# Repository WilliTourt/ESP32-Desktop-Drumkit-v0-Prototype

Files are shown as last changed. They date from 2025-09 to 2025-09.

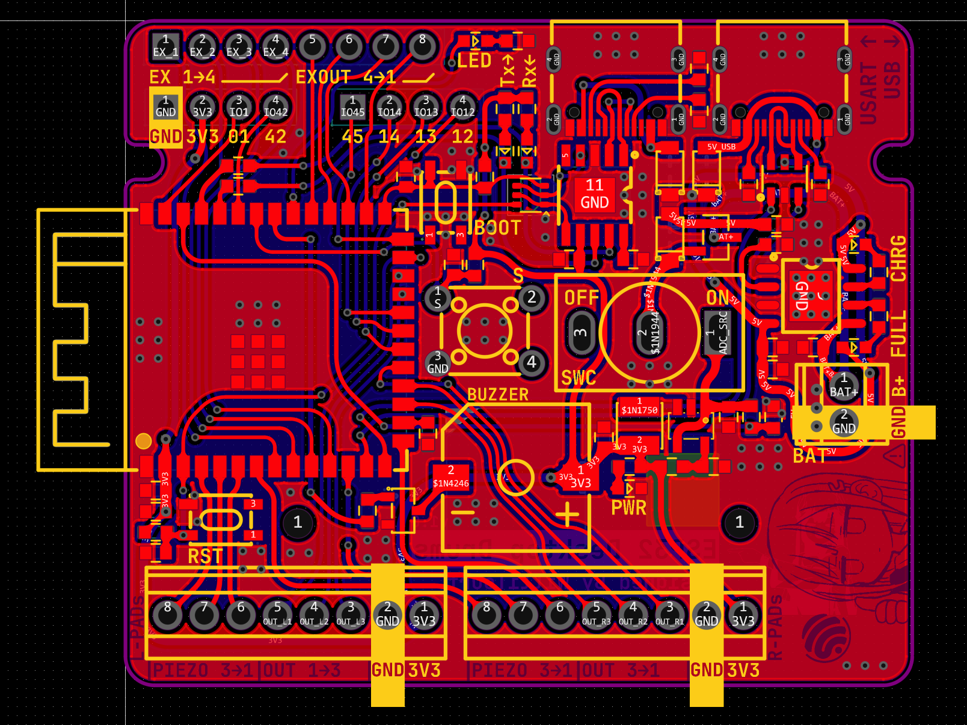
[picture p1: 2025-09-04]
Hardware_PCB/PCB Gerber/Images/ESP32 Top.png

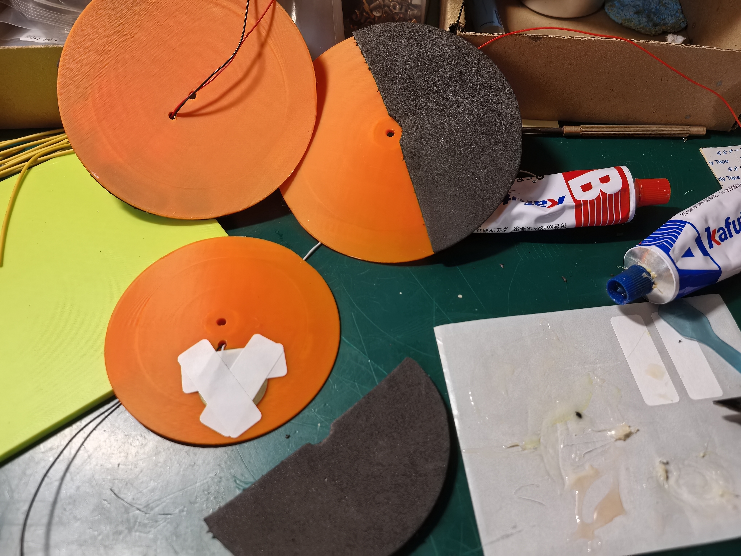
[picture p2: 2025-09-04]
Images of Drumkit/IMG_20250831_165159.jpg

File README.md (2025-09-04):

# ESP32 Desktop Drumkit v0 Prototype

> **Languages/语言**: [English](README.md) | [简体中文](README-zh-CN.md)

This is the English version of the README.

## Project Overview

This is an ESP32-based electronic drum pad prototype project supporting both BLE MIDI and serial MIDI output. The project includes multi-channel piezo drum pad/cymbal sensing, velocity normalization, dual-mode output (serial & BLE), and battery management.  
This project is suitable for DIY music enthusiasts, electronic drum developers, and embedded system learners for reference and further development.

---

## Features

- **Multi-Pad Sensing**: Supports multiple piezo sensors (drum pads, cymbals), each with independent threshold settings.
- **MIDI Output**:
  - **BLE MIDI** (wireless connection to phones/computers)
  - **Serial MIDI** (connects to PC via CH340/USB-to-serial, supported by Hairless MIDI bridge software)
- **Velocity Normalization**: Maps detected strike intensity to standard MIDI velocity (1-127).
- **Anti-Crosstalk Algorithm**: Only allows the pad with the highest ADC value to trigger during each sampling period, with silent periods for other pads to prevent false triggers.
- **Battery Voltage Management**: Supports battery monitoring and low-power alerts.
- **LED/Buzzer Indicators**: Mode switching and status feedback.
- **One-Button Mode Switching**: Toggle between BLE MIDI and Serial MIDI modes.
- **Enclosure Design**: Modular design for easy expansion.

---

## Hardware Specifications

- **Main Controller**: ESP32 (ESP32-S3 recommended for native USB support)
- **Piezo Elements**: ≥42mm for drum pads, 27mm for cymbals; *strongly* recommend shielded signal wires with parallel 0.1μF~1μF ceramic capacitors
- **Serial Chip**: CH340 (or other USB-UART converters)
- **Battery**: Optional lithium battery with voltage monitoring circuit
- **Others**: LEDs, buzzer, buttons - see `def.h` for peripheral interfaces
- 
### Sensor Connection/External Circuit

- Refer to [Images of Drumkit](https://github.com/WilliTourt/ESP32-Desktop-Drumkit-v0-Prototype/tree/main/Images%20of%20Drumkit) and [Hardware_PCB](https://github.com/WilliTourt/ESP32-Desktop-Drumkit-v0-Prototype/tree/main/Hardware_PCB)
- The external circuit uses quick-connect plugs to interface piezo elements through a simple voltage divider board before connecting to the main controller
- Main board IOs are labeled PIEZO (ADC input for piezo elements) and OUT (originally intended for LED effects but unused in this prototype)

### 3D Enclosure Files

- Final assembled appearance shown in [Images of Drumkit](https://github.com/WilliTourt/ESP32-Desktop-Drumkit-v0-Prototype/tree/main/Images%20of%20Drumkit)
- Designed as a miniature version of a real electronic drum set
- Main flaw: pads/cymbals don't properly account for vibration transmission
- Base plate split into L/R sections due to 3D printer size limitations
- L/R circuits connected via magnetic connectors (2/4-pin with screw holes, producer: pogopin)

---

## Software Specifications

- **PlatformIO/Arduino compatible**, PlatformIO with Arduino framework recommended
- **Dependencies**:
  - `BLEMIDI_Transport` / `hardware/BLEMIDI_ESP32`
  - `OneButtonTiny` (button detection)
  - See source code headers for others

---

## Usage Instructions

### 1. Hardware Setup

- Connect piezo elements to GPIO as defined in `def.h`
- Connect serial TX/RX to computer via CH340 (recognized as COM port)
- BLE MIDI supports phone/computer Bluetooth connections
- Button for mode switching

### 2. Compilation & Flashing

- Using PlatformIO: `pio run -t upload`
- Or Arduino IDE: select correct board and port

### 3. MIDI Output

#### Serial MIDI

- Open [Hairless MIDI <-> Serial Bridge](https://projectgus.github.io/hairless-midiserial/) or [loopMIDI](https://www.tobias-erichsen.de/software/loopmidi.html)
- Set baud rate to 115200 (matches code)
- After bridging, DAW/audio software can recognize virtual MIDI port

#### BLE MIDI

- Connect Bluetooth device to "ESP32 Desktop DrumKit v0"
- DAW or mobile MIDI apps can directly recognize

### 4. Anti-Interference Notes

- Only the pad with highest ADC value triggers per sampling period, others enter silent period (software anti-crosstalk)
- Independent threshold settings for pads/cymbals (see `Pad` constructor parameters)
- For extreme false triggers, adjust thresholds, silent periods, or hardware voltage dividers/capacitors

---

## Code Structure

- `main.cpp`: Core logic, pad management, MIDI output and mode switching
- `pad.h` / `pad.cpp`: Pad object definition, sampling and trigger detection
- `def.h`: Hardware pin definitions, MIDI note mapping
- `OneButtonTiny.h` / `.cpp`: Button library
- `battery.h` / `.cpp`: Battery management
- Other supporting files

---

## Common Issues

1. **False triggers/missed triggers/multiple pads sounding**
   - Check hardware voltage dividers/capacitors/shielding
   - Increase pad thresholds, decrease cymbal thresholds
   - Software already implements max-ADC-value triggering + silent period protection

  *As this is my first instrument project, the hardware design didn't properly account for vibration transmission through piezo elements, leading to insensitive pads. The next version v1 will incorporate proper electronic drum structural design.*

2. **Serial MIDI not recognized as MIDI device by PC**  
   - Use Hairless MIDI or loopMIDI for serial-MIDI bridging

---

## Contribution/Customization Suggestions

- Modify `Pad` constructor parameters for finer per-pad threshold control
- Add more pads or implement double-tap/roll detection
- For native USB MIDI (no serial bridge), consider ESP32-S3 with TinyUSB library
- PRs and issues welcome

---

## Acknowledgments

- Thanks to all open-source library authors and the electronic drum DIY community
- Inspired by [Victor2805/Homemade-electronic-drum-kit-with-arduino](https://github.com/Victor2805/Homemade-electronic-drum-kit-with-arduino)
- Special thanks to my percussion-loving and DAW-expert cousin @[Woodbreeze](https://github.com/WoodBreeze) ;)
---

**WilliTourt / 2025.9 Prototype Release**

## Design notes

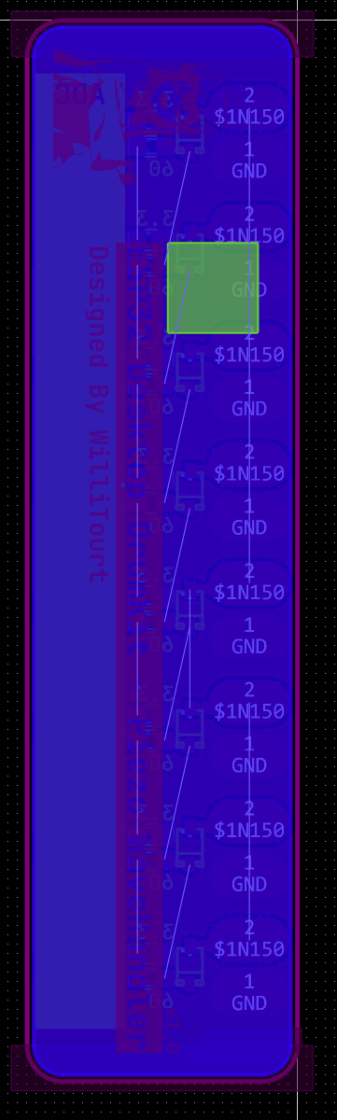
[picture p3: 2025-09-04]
Hardware_PCB/PCB Gerber/Images/Wave Bottom.png

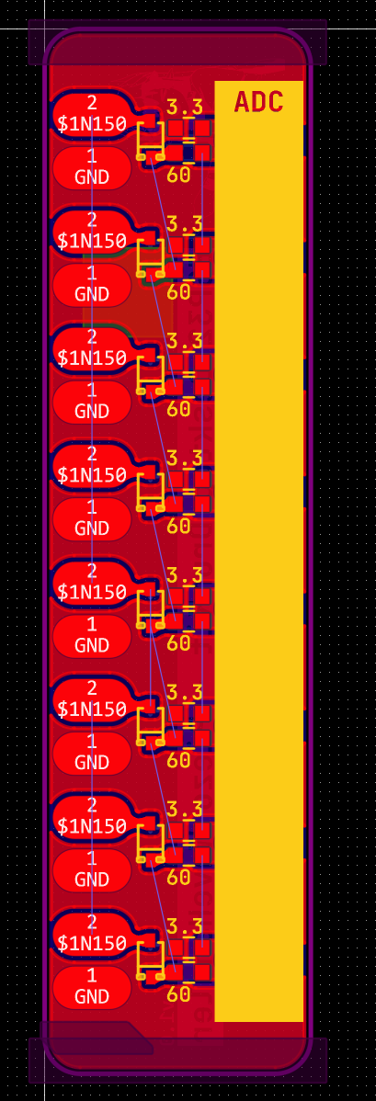
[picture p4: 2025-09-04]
Hardware_PCB/PCB Gerber/Images/Wave Top.png

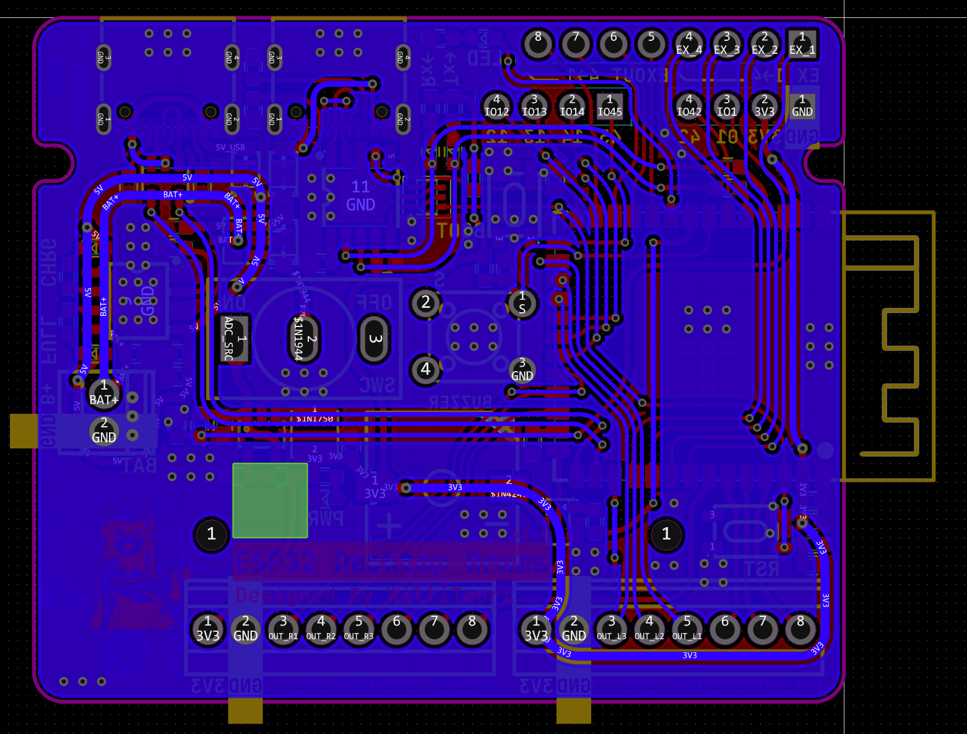
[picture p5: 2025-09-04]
Hardware_PCB/PCB Gerber/Images/ESP32 Bottom.png

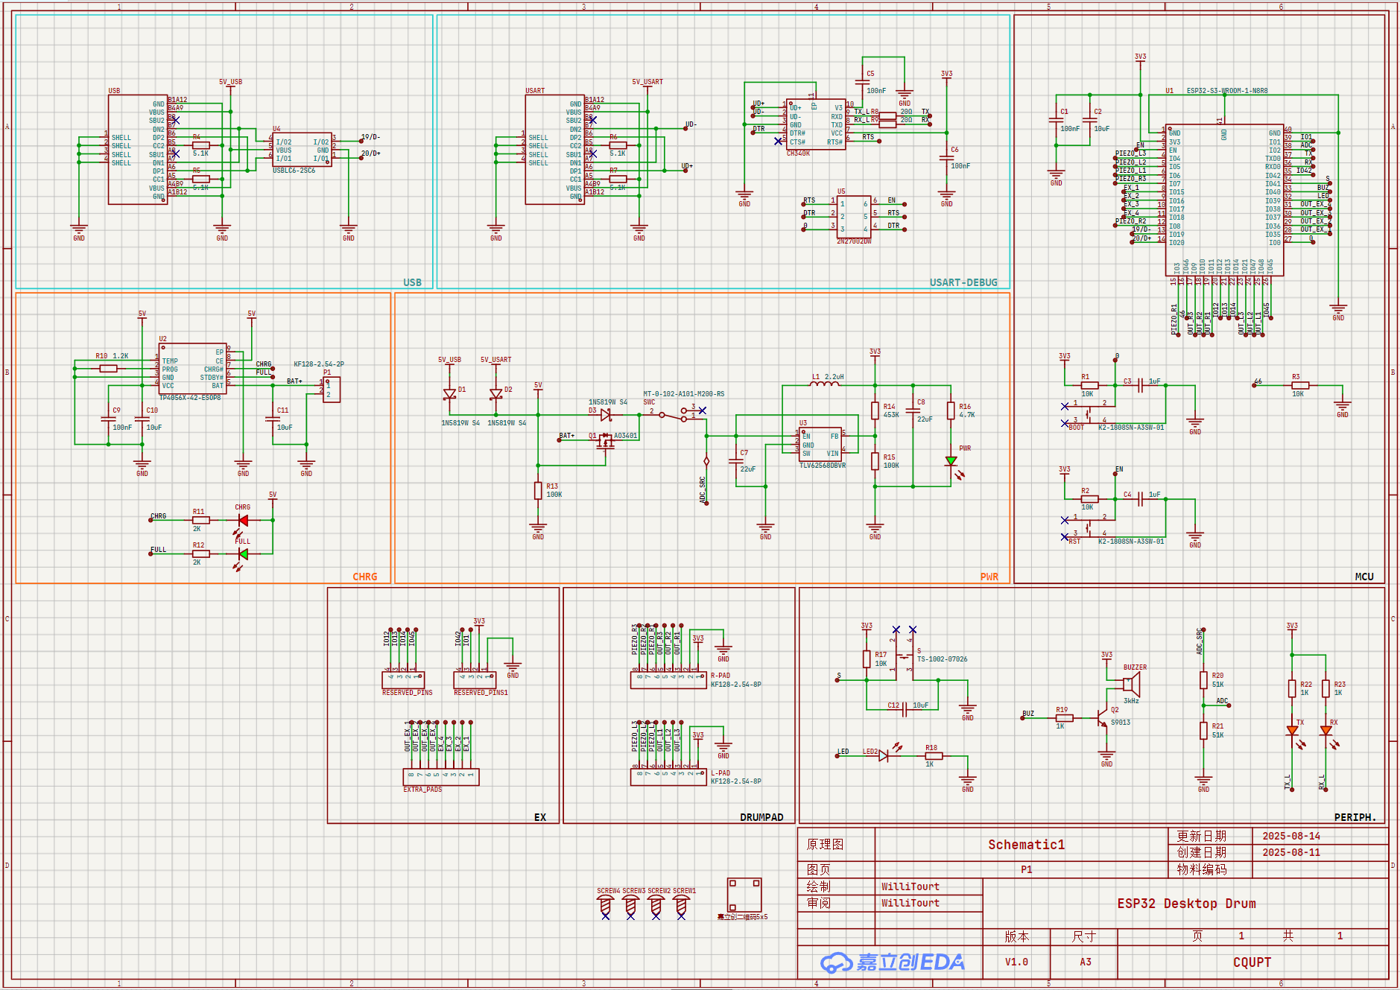
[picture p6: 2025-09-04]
Hardware_PCB/Schematic/ESP32 Board.png

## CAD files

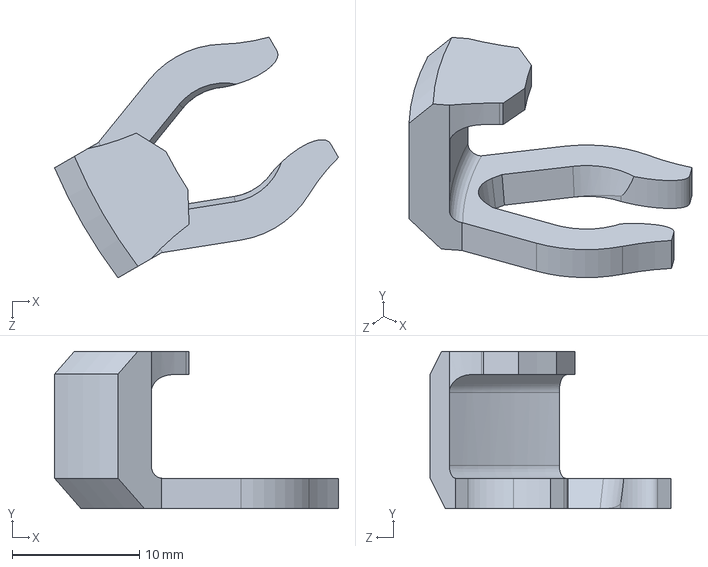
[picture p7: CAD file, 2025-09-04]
ESP32 Desktop Drumkit 3D Parts/Solidworks/DrumPad Fastener.SLDPRT
22.4 x 12.4 x 19.0 mm

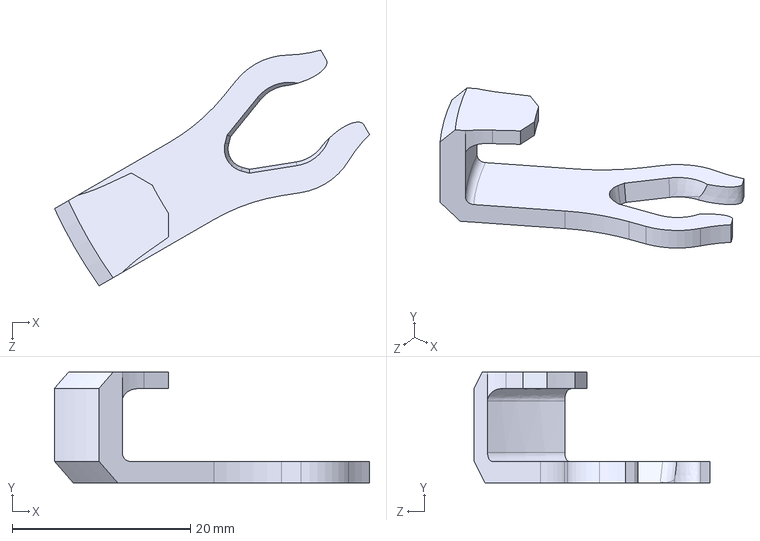
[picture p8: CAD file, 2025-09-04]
ESP32 Desktop Drumkit 3D Parts/STEP Files/DrumPad Fastener 10.STEP
35.3 x 12.4 x 26.4 mm

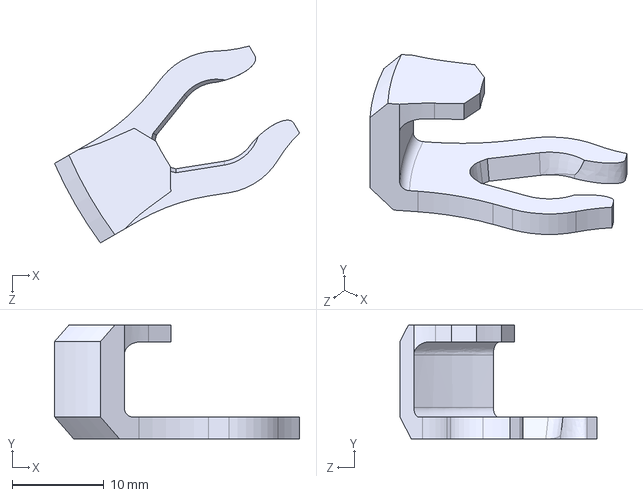
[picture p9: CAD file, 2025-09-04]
ESP32 Desktop Drumkit 3D Parts/STEP Files/DrumPad Fastener 08.STEP
26.7 x 12.4 x 21.5 mm

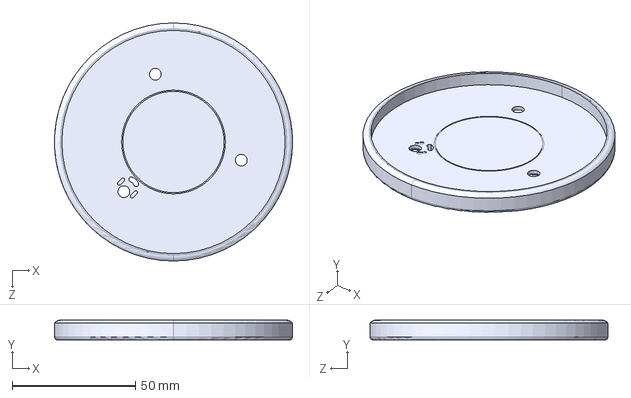
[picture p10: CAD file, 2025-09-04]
ESP32 Desktop Drumkit 3D Parts/STEP Files/DrumPad_9cm.STEP
96.4 x 8.00 x 96.4 mm

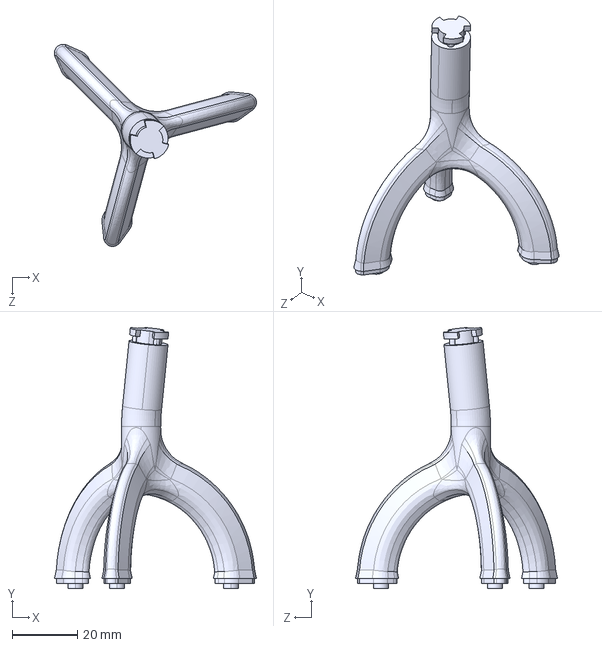
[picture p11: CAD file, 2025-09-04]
ESP32 Desktop Drumkit 3D Parts/STEP Files/DrumPad_Leg_Long.STEP
61.8 x 79.8 x 61.8 mm

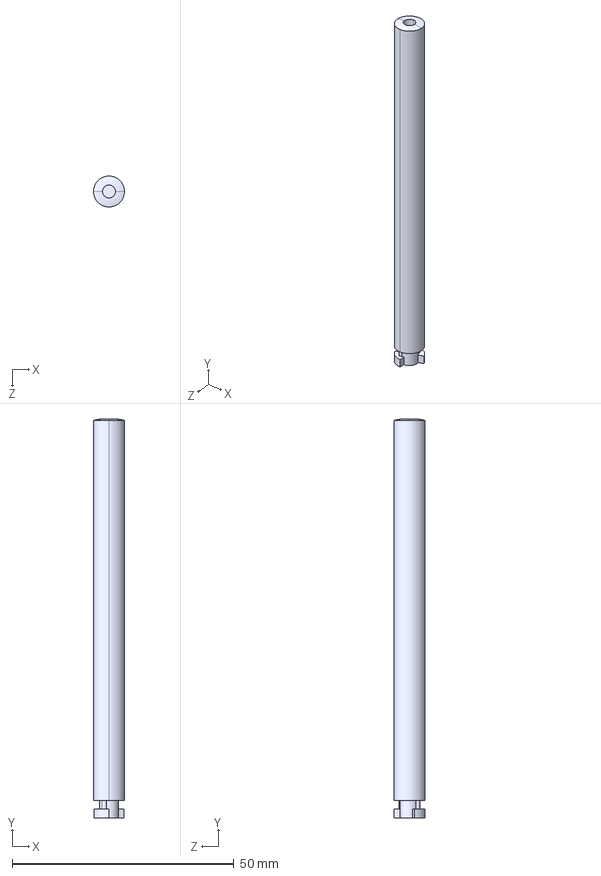
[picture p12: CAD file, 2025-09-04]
ESP32 Desktop Drumkit 3D Parts/STEP Files/Cymbal Stand_Short.STEP
7.00 x 90.0 x 7.00 mm

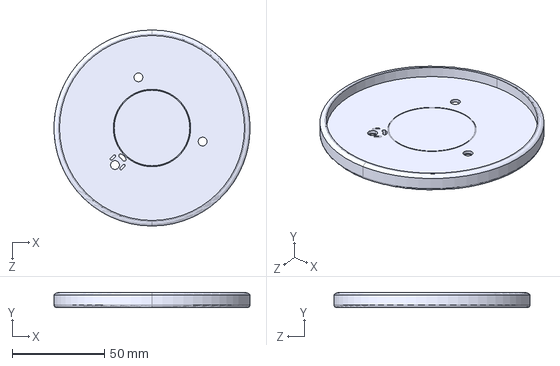
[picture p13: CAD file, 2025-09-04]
ESP32 Desktop Drumkit 3D Parts/STEP Files/DrumPad_10cm.STEP
106.4 x 8.00 x 106.4 mm

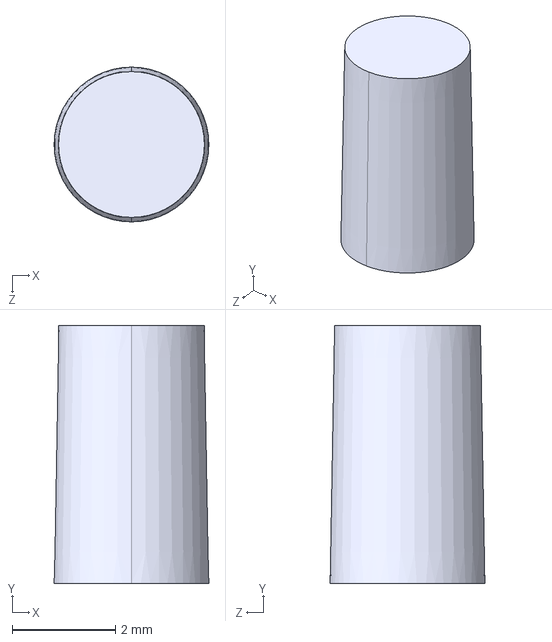
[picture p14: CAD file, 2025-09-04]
ESP32 Desktop Drumkit 3D Parts/STEP Files/BTN Ext.STEP
3.00 x 5.00 x 3.00 mm

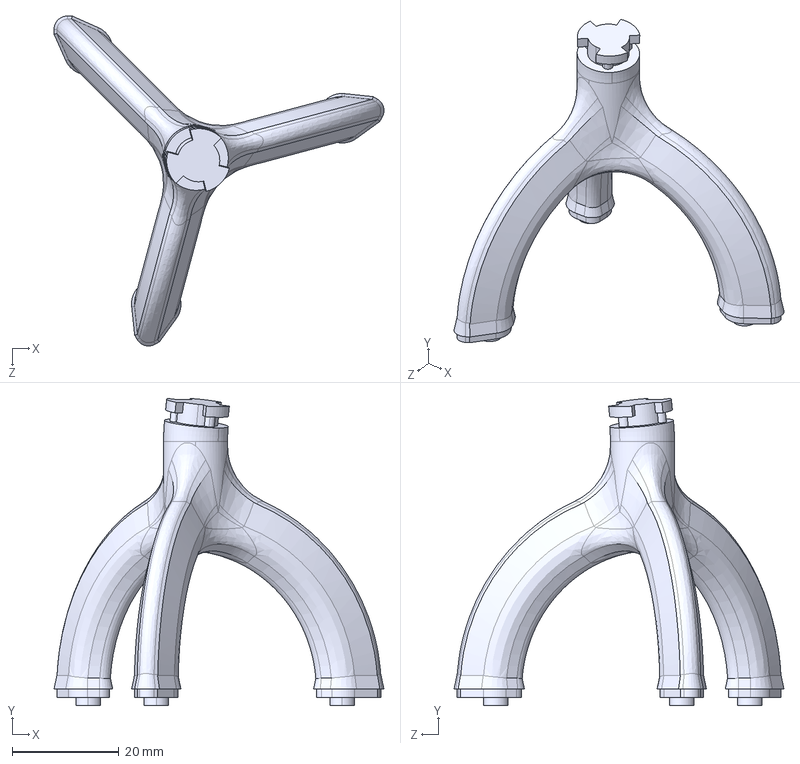
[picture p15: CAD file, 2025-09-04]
ESP32 Desktop Drumkit 3D Parts/STEP Files/DrumPad_Leg_Short.STEP
61.8 x 57.5 x 61.8 mm

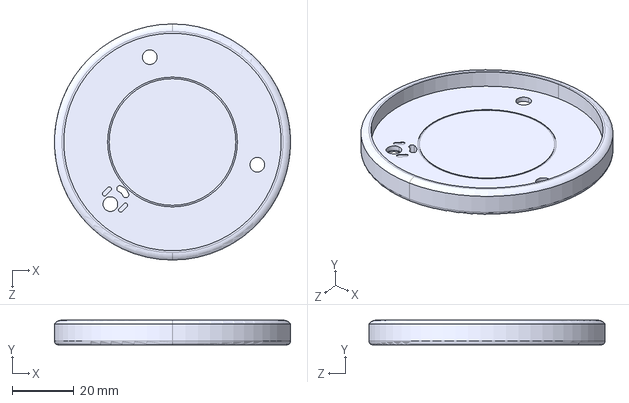
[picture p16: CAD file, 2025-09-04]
ESP32 Desktop Drumkit 3D Parts/STEP Files/DrumPad_7cm.STEP
76.4 x 8.00 x 76.4 mm

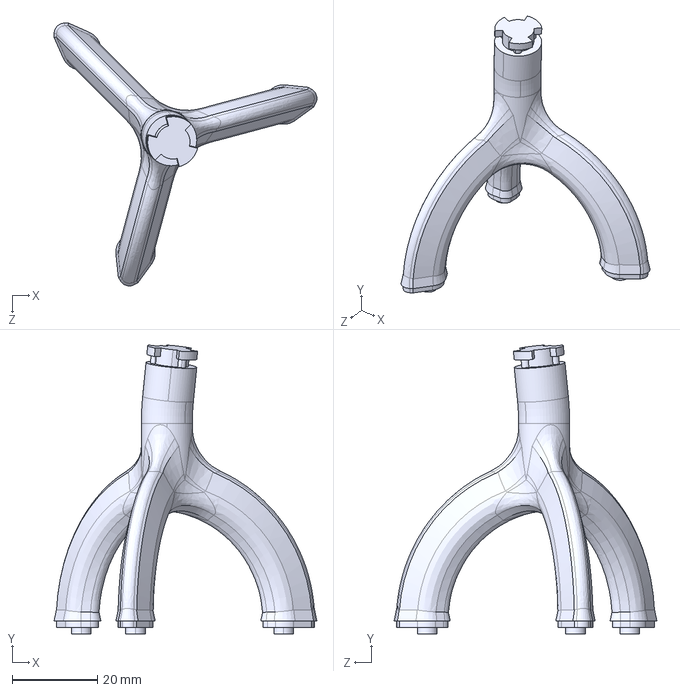
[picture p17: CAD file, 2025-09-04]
ESP32 Desktop Drumkit 3D Parts/STEP Files/DrumPad_Leg.STEP
61.8 x 67.9 x 61.8 mm

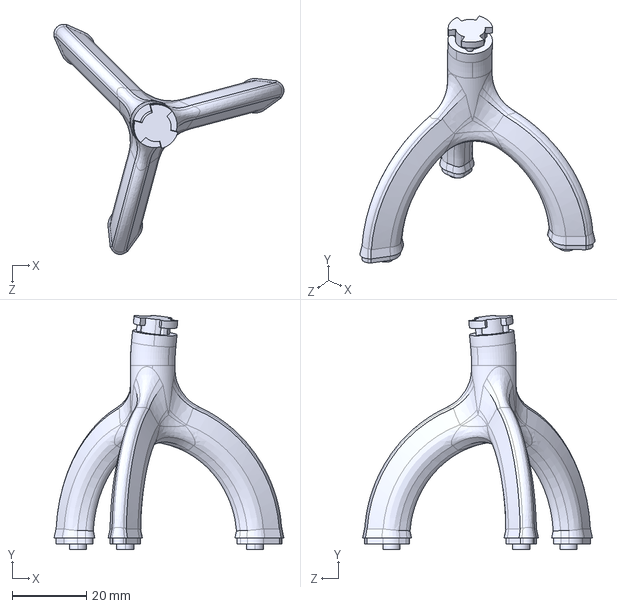
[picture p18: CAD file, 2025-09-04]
ESP32 Desktop Drumkit 3D Parts/STEP Files/DrumPad_Leg_Short+5.STEP
61.8 x 63.0 x 61.8 mm

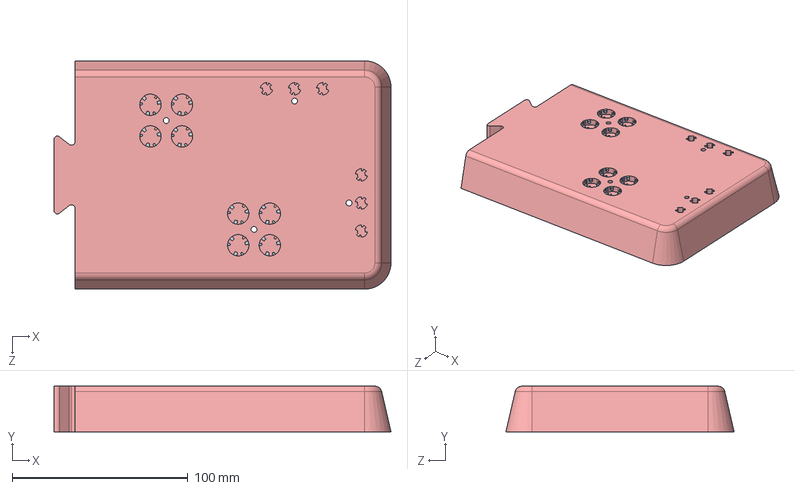
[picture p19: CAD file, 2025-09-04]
ESP32 Desktop Drumkit 3D Parts/STEP Files/Baseplate_R.STEP
191.9 x 26.0 x 130.0 mm

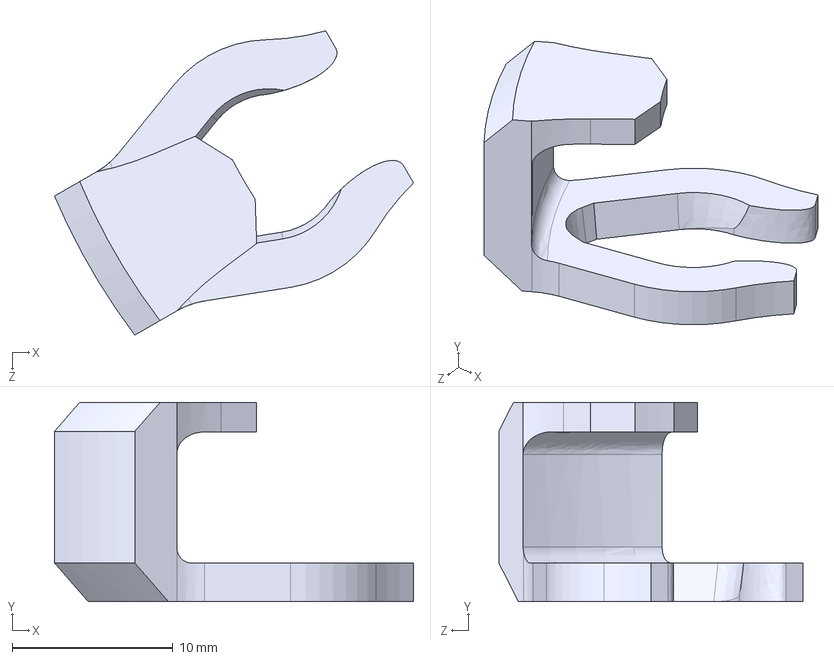
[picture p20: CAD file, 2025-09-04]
ESP32 Desktop Drumkit 3D Parts/STEP Files/DrumPad Fastener 07.STEP
22.4 x 12.4 x 19.0 mm

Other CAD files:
ESP32 Desktop Drumkit 3D Parts/Solidworks/Fastener Chk.SLDASM
ESP32 Desktop Drumkit 3D Parts/STEP Files/Cymbal_9cm.STEP
ESP32 Desktop Drumkit 3D Parts/STEP Files/CoverPlate_L.STEP
ESP32 Desktop Drumkit 3D Parts/STEP Files/DrumPad_Leg+5.STEP
ESP32 Desktop Drumkit 3D Parts/STEP Files/Baseplate_L.STEP
ESP32 Desktop Drumkit 3D Parts/STEP Files/CoverPlate_R.STEP
ESP32 Desktop Drumkit 3D Parts/STEP Files/Cymbal Stand.STEP
ESP32 Desktop Drumkit 3D Parts/STEP Files/Cymbal_11cm.STEP
ESP32 Desktop Drumkit 3D Parts/STEP Files/DrumPad Fastener 09.STEP
ESP32 Desktop Drumkit 3D Parts/STEP Files/DrumPad_8cm.STEP
ESP32 Desktop Drumkit 3D Parts/Solidworks/Baseplate_L.SLDPRT
ESP32 Desktop Drumkit 3D Parts/Solidworks/Baseplate_R.SLDPRT
ESP32 Desktop Drumkit 3D Parts/Solidworks/CoverPlate_L.SLDPRT
ESP32 Desktop Drumkit 3D Parts/Solidworks/CoverPlate_R.SLDPRT
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

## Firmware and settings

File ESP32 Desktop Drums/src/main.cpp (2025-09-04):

#include <Arduino.h>
#include <MIDI.h>
#include "BLEMIDI_Transport.h"
#include "hardware/BLEMIDI_ESP32.h"

// #include "UsbMidi.h"
// ALL COMMENTED LINES BELOW ARE USBMIDI RELATED CODE, 
// I switched to PLAN B: 
// Not using UsbMidi library, but using USART with a bridge program

#include "OneButtonTiny.h"
#include "battery.h"
#include "pad.h"
#include "def.h"

enum class MIDI_MODE { USBMIDI, BLEMIDI, SERIALMIDI };
MIDI_MODE current_mode = MIDI_MODE::BLEMIDI;
// bool is_usb_connected = false;
bool is_ble_connected = false;

bool setup_done = false;
bool mode_chng = false;
bool pads_need_update = false;
bool battery_update_flag = false;
bool blinker = false;

NoteOff_Flag_t NoteOffFlags[7] = {};

#define PAD_SILENCE_MS 10
uint32_t pad_silence_until = 0;

/* Notes used in the drumkit
	 L3  L2 	R2	R3
	   L1		  R1  R4
*/
// 38 - Acoustic Snare         L1
// 50 - High Tom               L2
// 46 - Open Hi-Hat            L3
// 45 - Low Tom                R1
// 47 - Low-Mid Tom            R2
// 51 - Ride Cymbal 1          R3
// 49 - Crash Cymbal 1         R4

const uint8_t PadType[7] = {
	ACOUSTIC_SNARE,
	HIGH_TOM      ,
	OPEN_HI_HAT   ,
	LOW_TOM       ,
	LOW_MID_TOM   ,
	CRASH_CYMBAL_1,
	RIDE_CYMBAL_1
};

#define DRUMPAD_THRESHOLD 220
#define CYMBAL_THRESHOLD 110
#define DRUMPAD_UPPER_THRESHOLD 3072
#define CYMBAL_UPPER_THRESHOLD 1024

// INST declarations ------------------------------------------------------//
Pad	snare_l1 (PIEZO_L1_PIN , OUT_L1_PIN , DRUMPAD_THRESHOLD, DRUMPAD_UPPER_THRESHOLD); // L1
Pad	  tom_l2 (PIEZO_L2_PIN , OUT_L2_PIN , DRUMPAD_THRESHOLD, DRUMPAD_UPPER_THRESHOLD); // L2
Pad	crash_l3 (PIEZO_L3_PIN , OUT_L3_PIN , CYMBAL_THRESHOLD , CYMBAL_UPPER_THRESHOLD ); // L3
Pad	  tom_r1 (PIEZO_R1_PIN , OUT_R1_PIN , DRUMPAD_THRESHOLD, DRUMPAD_UPPER_THRESHOLD); // R1
Pad	  tom_r2 (PIEZO_R2_PIN , OUT_R2_PIN , DRUMPAD_THRESHOLD, DRUMPAD_UPPER_THRESHOLD); // R2
Pad	crash_r3 (PIEZO_R3_PIN , OUT_EX1_PIN, CYMBAL_THRESHOLD , CYMBAL_UPPER_THRESHOLD ); // R3
Pad	 ride_r4 (PIEZO_EX1_PIN, OUT_R3_PIN , CYMBAL_THRESHOLD , CYMBAL_UPPER_THRESHOLD ); // R4

BLEMIDI_CREATE_INSTANCE("ESP32 Desktop DrumKit v0", MIDI)
// UsbMidi USBMIDI;
OneButtonTiny button(S_PIN, true, true);
// ------------------------------------------------------------------------//

// Function Prototypes ----------------------------------------------------//
void IRAM_ATTR PADs_Update_ISR();
void IRAM_ATTR BAT_Update_ISR();

void Blink() {
	digitalWrite(LED_PIN, HIGH);
	delay(60);
	digitalWrite(LED_PIN, LOW);
}

void Beep() {
	digitalWrite(BUZZER_PIN, HIGH);
	delay(60);
	digitalWrite(BUZZER_PIN, LOW);
}

// https://midi.org/expanded-midi-1-0-messages-list
void Serial_SendMIDI(uint8_t note, uint8_t velocity, uint8_t channel = 10) {
    Serial.write(0x90 | ((channel - 1) & 0x0F));
    Serial.write(note & 0x7F);
    Serial.write(velocity & 0x7F);
}

void PAD_SendNoteOff(uint8_t i) {
	if (NoteOffFlags[i].noteOn_sent && (millis() - NoteOffFlags[i].noteOn_timestamp > NOTE_OFF_DELAY_MS)) {
		if (current_mode == MIDI_MODE::BLEMIDI && is_ble_connected) {
			MIDI.sendNoteOn(NoteOffFlags[i].note, 0, NoteOffFlags[i].channel);
		} else if (current_mode == MIDI_MODE::SERIALMIDI) {
			Serial.write(0x80 | ((NoteOffFlags[i].channel - 1) & 0x0F));
			Serial.write(NoteOffFlags[i].note & 0x7F);
			Serial.write(0x00);
		}
		NoteOffFlags[i].noteOn_sent = false;
	}
}

void Callback_BLE_Connected()    { is_ble_connected = true; }
void Callback_BLE_Disconnected() { is_ble_connected = false; }
void Callback_NoteOn(byte channel, byte note, byte velocity) {}
// void Callback_USB_Connected()    { is_usb_connected = true; }
// void Callback_USB_Disconnected() { is_usb_connected = false; }

void Callback_ButtonSingleClick() {
	if (current_mode == MIDI_MODE::BLEMIDI) {
		// current_mode = MIDI_MODE::USBMIDI;
		current_mode = MIDI_MODE::SERIALMIDI;
		Beep();
	} else {
		current_mode = MIDI_MODE::BLEMIDI;
		Beep();
		delay(100);
		Beep();
	}
	mode_chng = true;
}
// ------------------------------------------------------------------------//


void setup() {
	
	// setCpuFrequencyMhz(240);
	pinMode(DEBUG_PIN, OUTPUT);

	pinMode(LED_PIN, OUTPUT);
	pinMode(BUZZER_PIN, OUTPUT);

	BLEMIDI.setHandleConnected(Callback_BLE_Connected);
	BLEMIDI.setHandleDisconnected(Callback_BLE_Disconnected);
	MIDI.begin();
	MIDI.setHandleNoteOn(Callback_NoteOn);

	// USBMIDI.begin();
	// USBMIDI.onDeviceConnected(Callback_USB_Connected);
	// USBMIDI.onDeviceDisconnectbd(Callback_USB_Disconnected);

	button.setClickMs(200);
	button.setDebounceMs(25);
	button.attachClick(Callback_ButtonSingleClick);

	// Timer for PADs update
	hw_timer_t* timer = timerBegin(0, 80, true);
    timerAttachInterrupt(timer, &PADs_Update_ISR, true);
    timerAlarmWrite(timer, 100, true);            			// 100 us (80Mhz clk)
    timerAlarmEnable(timer);

	// Timer for BAT update
	hw_timer_t* timer1 = timerBegin(1, 80, true);
    timerAttachInterrupt(timer1, &BAT_Update_ISR, true);
    timerAlarmWrite(timer1, 1000000, true);         		// 1s
    timerAlarmEnable(timer1);

	Serial.begin(115200);

	digitalWrite(LED_PIN, HIGH);
	digitalWrite(BUZZER_PIN, HIGH);
	delay(500);
	digitalWrite(LED_PIN, LOW);
	digitalWrite(BUZZER_PIN, LOW);

	setup_done = true;
}

void loop() {

	button.tick();

	// if (!mode_chng && current_mode == MIDI_MODE::USBMIDI) {
	// 	USBMIDI.update();
	// }

	if (pads_need_update && setup_done) {
		pads_need_update = false;

		Pad* pads[7] = {&snare_l1, &tom_l2, &crash_l3, &tom_r1, &tom_r2, &crash_r3, &ride_r4 };

        for (uint8_t i = 0; i < 7; i++) {
            pads[i]->updateForce();
        }

		// pads[0]->doADCRead(); // For Debugging

		if (millis() > pad_silence_until) {
			for (uint8_t i = 0; i < 7; i++) {

				// L3 and R3 has INTERFERENCE issue, skip for now :(
				if (i == 2 || i == 5) { continue; }

				if (pads[i]->isTriggered()) {
					uint8_t velocity = pads[i]->getVelocity();
					uint8_t note = PadType[i];
					uint8_t channel = 10;

					if (current_mode == MIDI_MODE::BLEMIDI && is_ble_connected) {
						MIDI.sendNoteOn(note, velocity, channel);
					// } else if (current_mode == MIDI_MODE::USBMIDI && is_usb_connected) {
					// 	USBMIDI.noteOn(PadType[i], velocity, 1);
					} else if (current_mode == MIDI_MODE::SERIALMIDI) {
						Serial_SendMIDI(note, velocity, channel);
					}

					NoteOffFlags[i].noteOn_sent = true;
					NoteOffFlags[i].noteOn_timestamp = millis();
					NoteOffFlags[i].note = note;
					NoteOffFlags[i].channel = channel;

					pad_silence_until = millis() + PAD_SILENCE_MS;
				}
			}
		}
	}

	if (mode_chng) {
		pads_need_update = false;
		setup_done = false;
		if (current_mode == MIDI_MODE::BLEMIDI) {
			// USBMIDI.end();
			// delay(30);
			BLEMIDI.begin();
			BLEMIDI.setHandleConnected(Callback_BLE_Connected);
			BLEMIDI.setHandleDisconnected(Callback_BLE_Disconnected);
			MIDI.setHandleNoteOn(Callback_NoteOn);
		} else {
			BLEMIDI.end();
			delay(30);
			// USBMIDI.begin();
			// USBMIDI.onDeviceConnected(Callback_USB_Connected);
			// USBMIDI.onDeviceDisconnected(Callback_USB_Disconnected);
		}

		Blink();
		mode_chng = false;
		setup_done = true;
	}

	for (uint8_t i = 0; i < 7; i++) {
		PAD_SendNoteOff(i);
	}

	// if (battery_update_flag) {
	// 	battery_update_flag = false;
	// 	battery.read();
	// }

	// if (battery.isLow() && blinker) {
	// 	Beep();
	// }
}

void IRAM_ATTR PADs_Update_ISR() {
	if (setup_done) { pads_need_update = true; }
}

void IRAM_ATTR BAT_Update_ISR() {
    // battery_update_flag = true;
	// blinker = !blinker;
}

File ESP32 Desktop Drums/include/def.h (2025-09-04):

/*
    Pin definitions for the ESP32 Desktop Drums project.
*/
#pragma once

#define DEBUG_PIN 1

// ADC
#define ADC_PIN 2

// Basic
#define LED_PIN 39
#define BUZZER_PIN 40
#define S_PIN 41

// Piezos & Outputs
#define PIEZO_L3_PIN 4
#define PIEZO_L2_PIN 5
#define PIEZO_L1_PIN 6
#define OUT_L3_PIN 21
#define OUT_L2_PIN 47
#define OUT_L1_PIN 48

#define PIEZO_R3_PIN 7
#define PIEZO_R2_PIN 8
#define PIEZO_R1_PIN 3
#define OUT_R3_PIN 9
#define OUT_R2_PIN 10
#define OUT_R1_PIN 11

#define PIEZO_EX1_PIN 15
#define PIEZO_EX2_PIN 16
#define PIEZO_EX3_PIN 17
#define PIEZO_EX4_PIN 18
#define OUT_EX1_PIN 35
#define OUT_EX2_PIN 36
#define OUT_EX3_PIN 37
#define OUT_EX4_PIN 38
